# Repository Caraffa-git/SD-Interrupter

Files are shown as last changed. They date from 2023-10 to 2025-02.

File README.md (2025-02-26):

# Tesla coil MIDI interrupter
It's modified version of [OneTesla SD interrupter](https://onetesla.com/).
To compile original software you have to install [SdFat v1.1.4](https://github.com/greiman/SdFat/releases/tag/1.1.4) library.


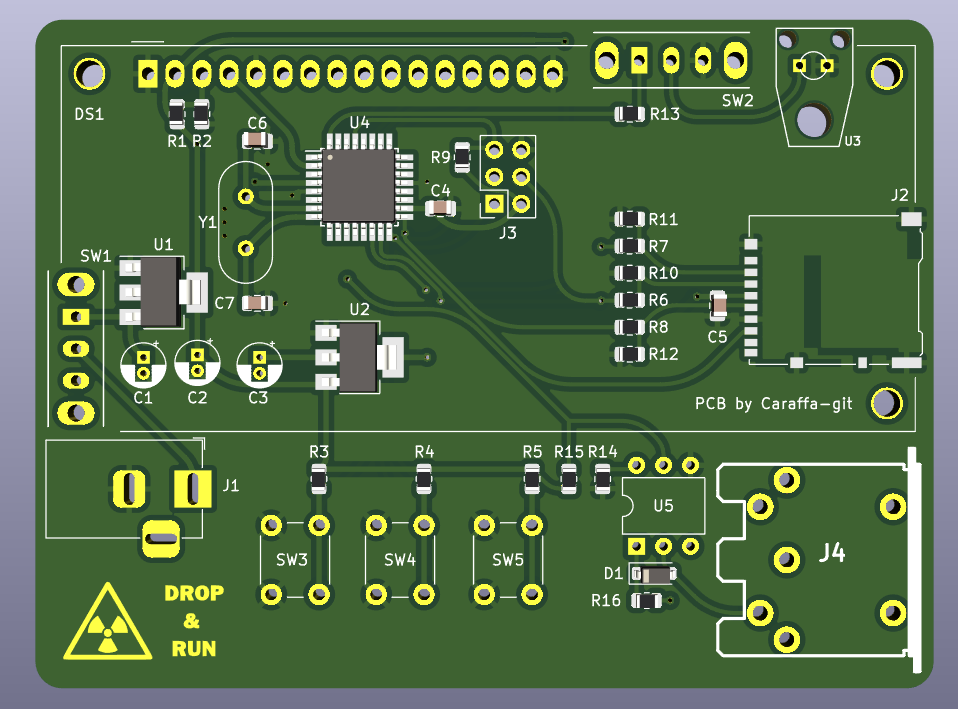
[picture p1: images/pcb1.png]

<!-- ![](./images/pcb2.png) -->

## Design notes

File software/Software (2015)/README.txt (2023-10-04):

This is the source and binary distribution for the oneTeslaTS SD card interrupter. Most users do not need to download this file - this package is useful only if you are modifying or reflashing your ATMega firmware.

==Description==

The SD card interrupter is designed to be a full-featured interrupter with support for live MIDI streaming and playback of local files stored on an SD card. Great care was taken to ensure that all source remained Arduino-compatible, and that the entire firmware would run on a single ATMega328 microcontroller. It features:

*Streaming from MIDI devices, including computers and keyboards.
*Playback of MIDI-like files ("OMD") from a micro SD card.
*Fixed mode with precise timer-based frequency control down to 1Hz.
*Small firmware size using fixed-point math, no softfloat libraries or FPU needed.

==Building==

This firmware has been developed on Arduino 1.0.3. We do not recommend using other versions due to Arduino's occasional tendency to break backwards compatibility. You will need to copy the libraries in inc/ to arduino-1.0.3/libraries. After that, it should be as simple as opening src/main/main.ino and clicking "Verify/Compile" in the Arduino IDE.

==Compatibility==

The interrupter is compatible with MicroSD/SDHC cards formatted with a FAT16 or FAT32 filesystem. Long filenames up to 99 characters are supported, as well as support for one level of directory.

==File description==

src/main
    |------ constants.h: assorted user-adjustable compile-time settings
    |------ data.h: include file for global variables
    |------ datatypes.h: program data structures
    |------ lcd.h, lcd.cpp: abstraction layer for the display; currently just a wrapper around Arduino's libraries.
    |------ main.ino: the main program loops
    |------ player.h, player.cpp: MIDI event handlers
    |------ sdsource.h, sdsource.cpp: SD card MIDI source
    |------ serialsource.h, serialsource.cpp: Hardware MIDI source
    |------ system.h, system.cpp: nonportable ATMega-specific routines
    |------ timers.h, timers.cpp: nonportable ATMega-specific ISR's
    |------ util.h, util.cpp: various utility functions

inc/
    |------ LiquidCrystal: Hitachi LCD driver library
    |------ PFFS: Petit FatFS filesystem driver
    |------ SdFat: Full featured FAT32 library

bin/
    |------ SDinterrupter.hex: pre-compiled binary for your convenience

omd/
    |------ omdconvert/
    |            |------ improv/: Improv MIDI library
    |            |------ omdconvert.exe: MIDI to OMD converter
    |            |------ omdconvert: Mac version of the converter
    |            |------ omdconvert.cpp: Source for the converter
    |            |------ README.txt: README for the converter
    |
    |------ *.mid, *.OMD: sample files

README.txt: this file :)

==CREDITS==
Props to the writers of Improv, PFFS, and SdFAT for making this possible. Special mention to Stridera on our forums, who implemented SDHC support and a bunch of neat fixes.

==LICENSING==

The libraries in inc/ are licensed under their authors' respective licensing. You are free to modify and redistribute the source and binaries found in this package for NONCOMMERCIAL USE as long as credit is given and this notice is included. Please note that in doing so, you give oneTesla, LLC nonexclusive, royalty-free license to use any such modifications for any purpose.

(We're normally not a fan of no-commercial-use source licenses as it hinders the usefulness of the code, but here we believe it is reasonable since it prevents others from unfairly mooching off our hard work while still leaving the source available for the community to use. For commerical use please contact us for further licensing terms, and we can probably work something out.)

==LEGAL DISCLAIMER==

Disclaimer of Warranty.
THERE IS NO WARRANTY FOR THE PROGRAM, TO THE EXTENT PERMITTED BY APPLICABLE LAW. EXCEPT WHEN OTHERWISE STATED IN WRITING THE COPYRIGHT HOLDERS AND/OR OTHER PARTIES PROVIDE THE PROGRAM “AS IS” WITHOUT WARRANTY OF ANY KIND, EITHER EXPRESSED OR IMPLIED, INCLUDING, BUT NOT LIMITED TO, THE IMPLIED WARRANTIES OF MERCHANTABILITY AND FITNESS FOR A PARTICULAR PURPOSE. THE ENTIRE RISK AS TO THE QUALITY AND PERFORMANCE OF THE PROGRAM IS WITH YOU. SHOULD THE PROGRAM PROVE DEFECTIVE, YOU ASSUME THE COST OF ALL NECESSARY SERVICING, REPAIR OR CORRECTION.

Limitation of Liability.
IN NO EVENT UNLESS REQUIRED BY APPLICABLE LAW OR AGREED TO IN WRITING WILL ANY COPYRIGHT HOLDER, OR ANY OTHER PARTY WHO MODIFIES AND/OR CONVEYS THE PROGRAM AS PERMITTED ABOVE, BE LIABLE TO YOU FOR DAMAGES, INCLUDING ANY GENERAL, SPECIAL, INCIDENTAL OR CONSEQUENTIAL DAMAGES ARISING OUT OF THE USE OR INABILITY TO USE THE PROGRAM (INCLUDING BUT NOT LIMITED TO LOSS OF DATA OR DATA BEING RENDERED INACCURATE OR LOSSES SUSTAINED BY YOU OR THIRD PARTIES OR A FAILURE OF THE PROGRAM TO OPERATE WITH ANY OTHER PROGRAMS), EVEN IF SUCH HOLDER OR OTHER PARTY HAS BEEN ADVISED OF THE POSSIBILITY OF SUCH DAMAGES.

If the disclaimer of warranty and limitation of liability provided above cannot be given local legal effect according to their terms, reviewing courts shall apply local law that most closely approximates an absolute waiver of all civil liability in connection with the Program, unless a warranty or assumption of liability accompanies a copy of the Program in return for a fee.

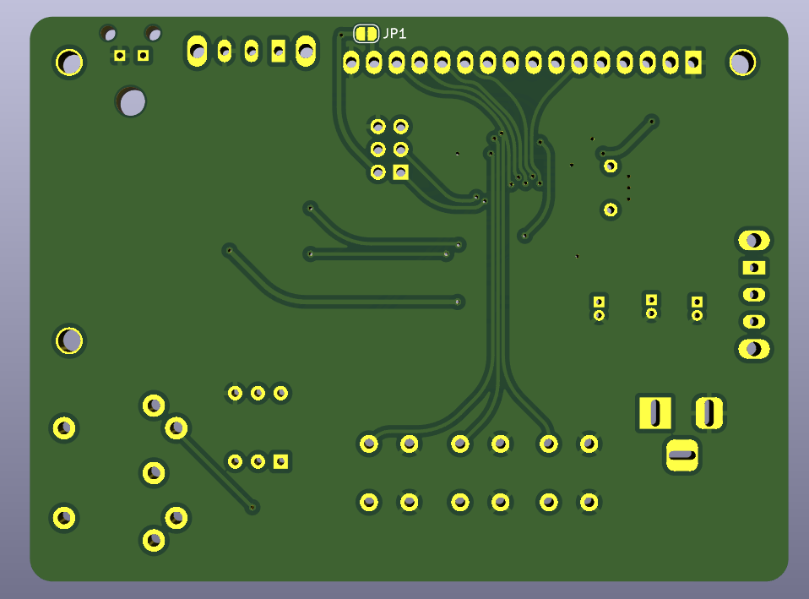
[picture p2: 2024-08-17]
images/pcb2.png

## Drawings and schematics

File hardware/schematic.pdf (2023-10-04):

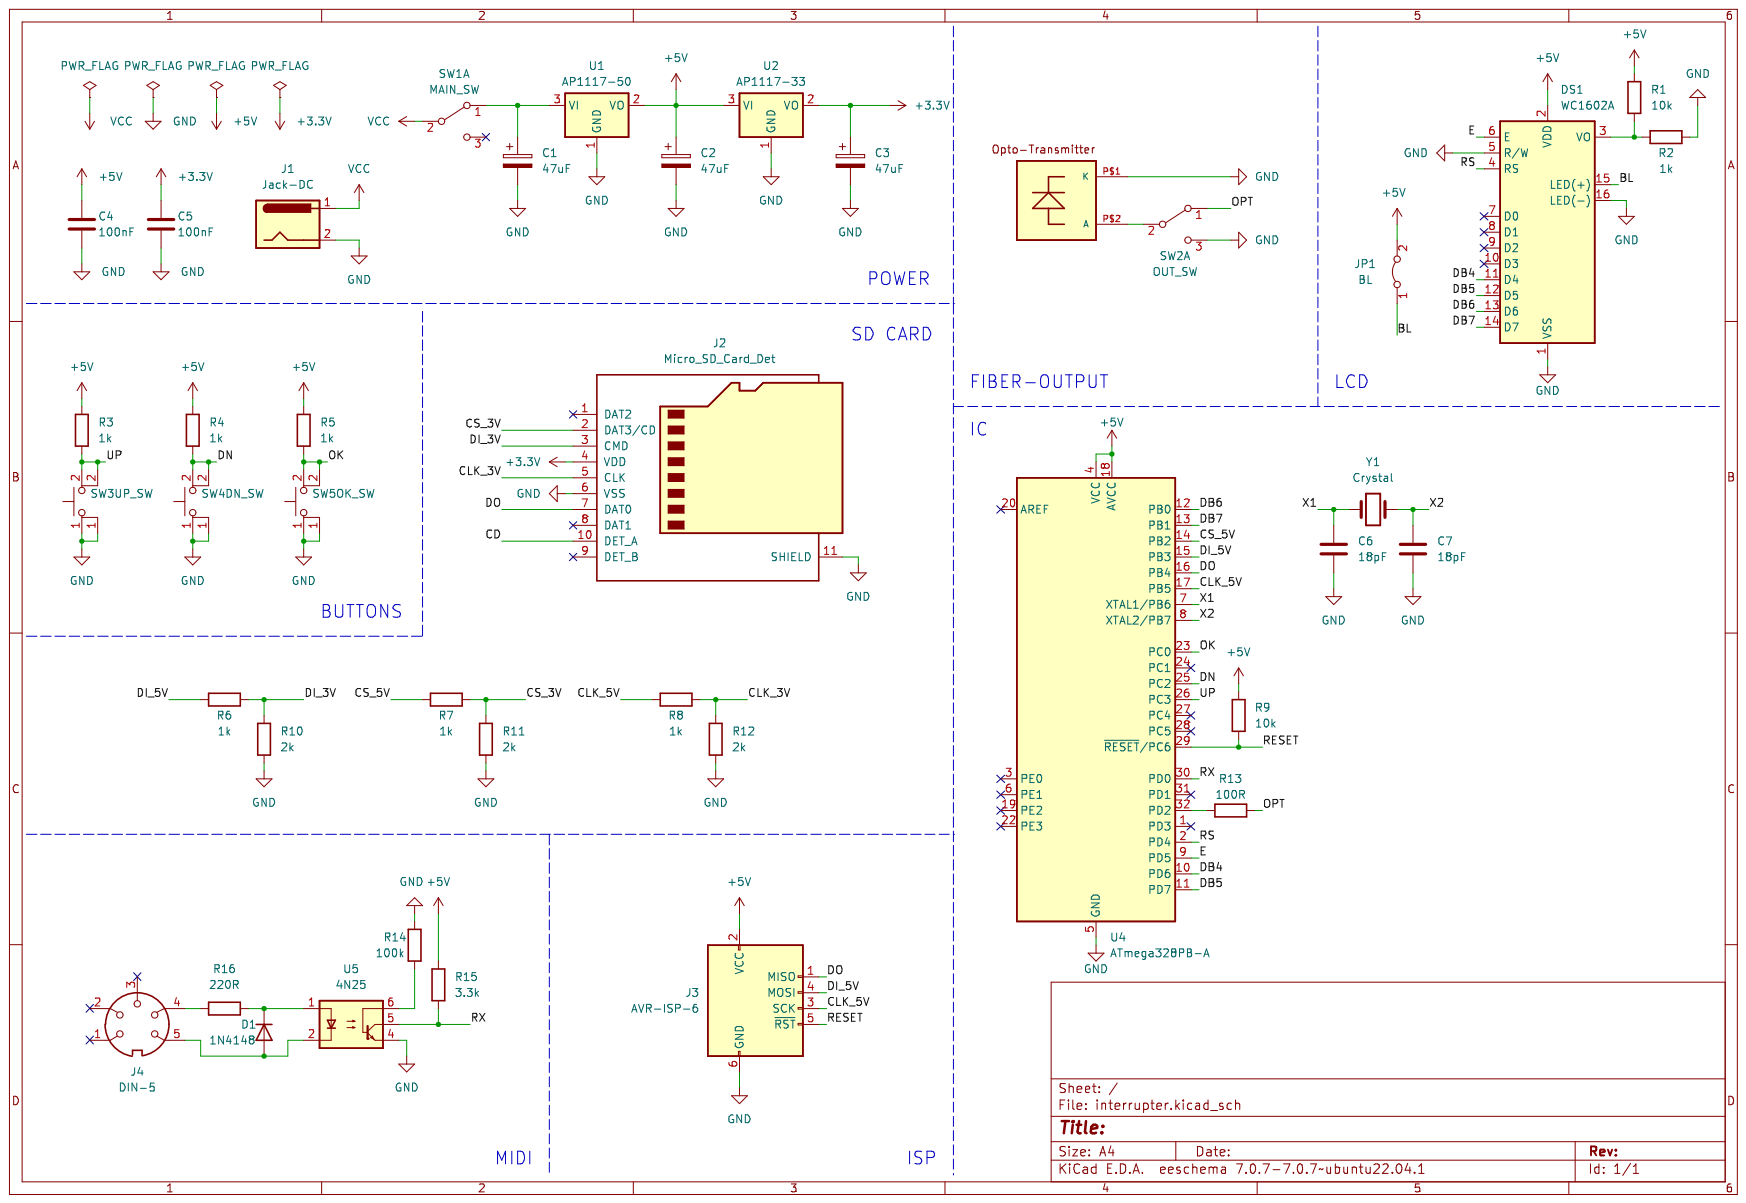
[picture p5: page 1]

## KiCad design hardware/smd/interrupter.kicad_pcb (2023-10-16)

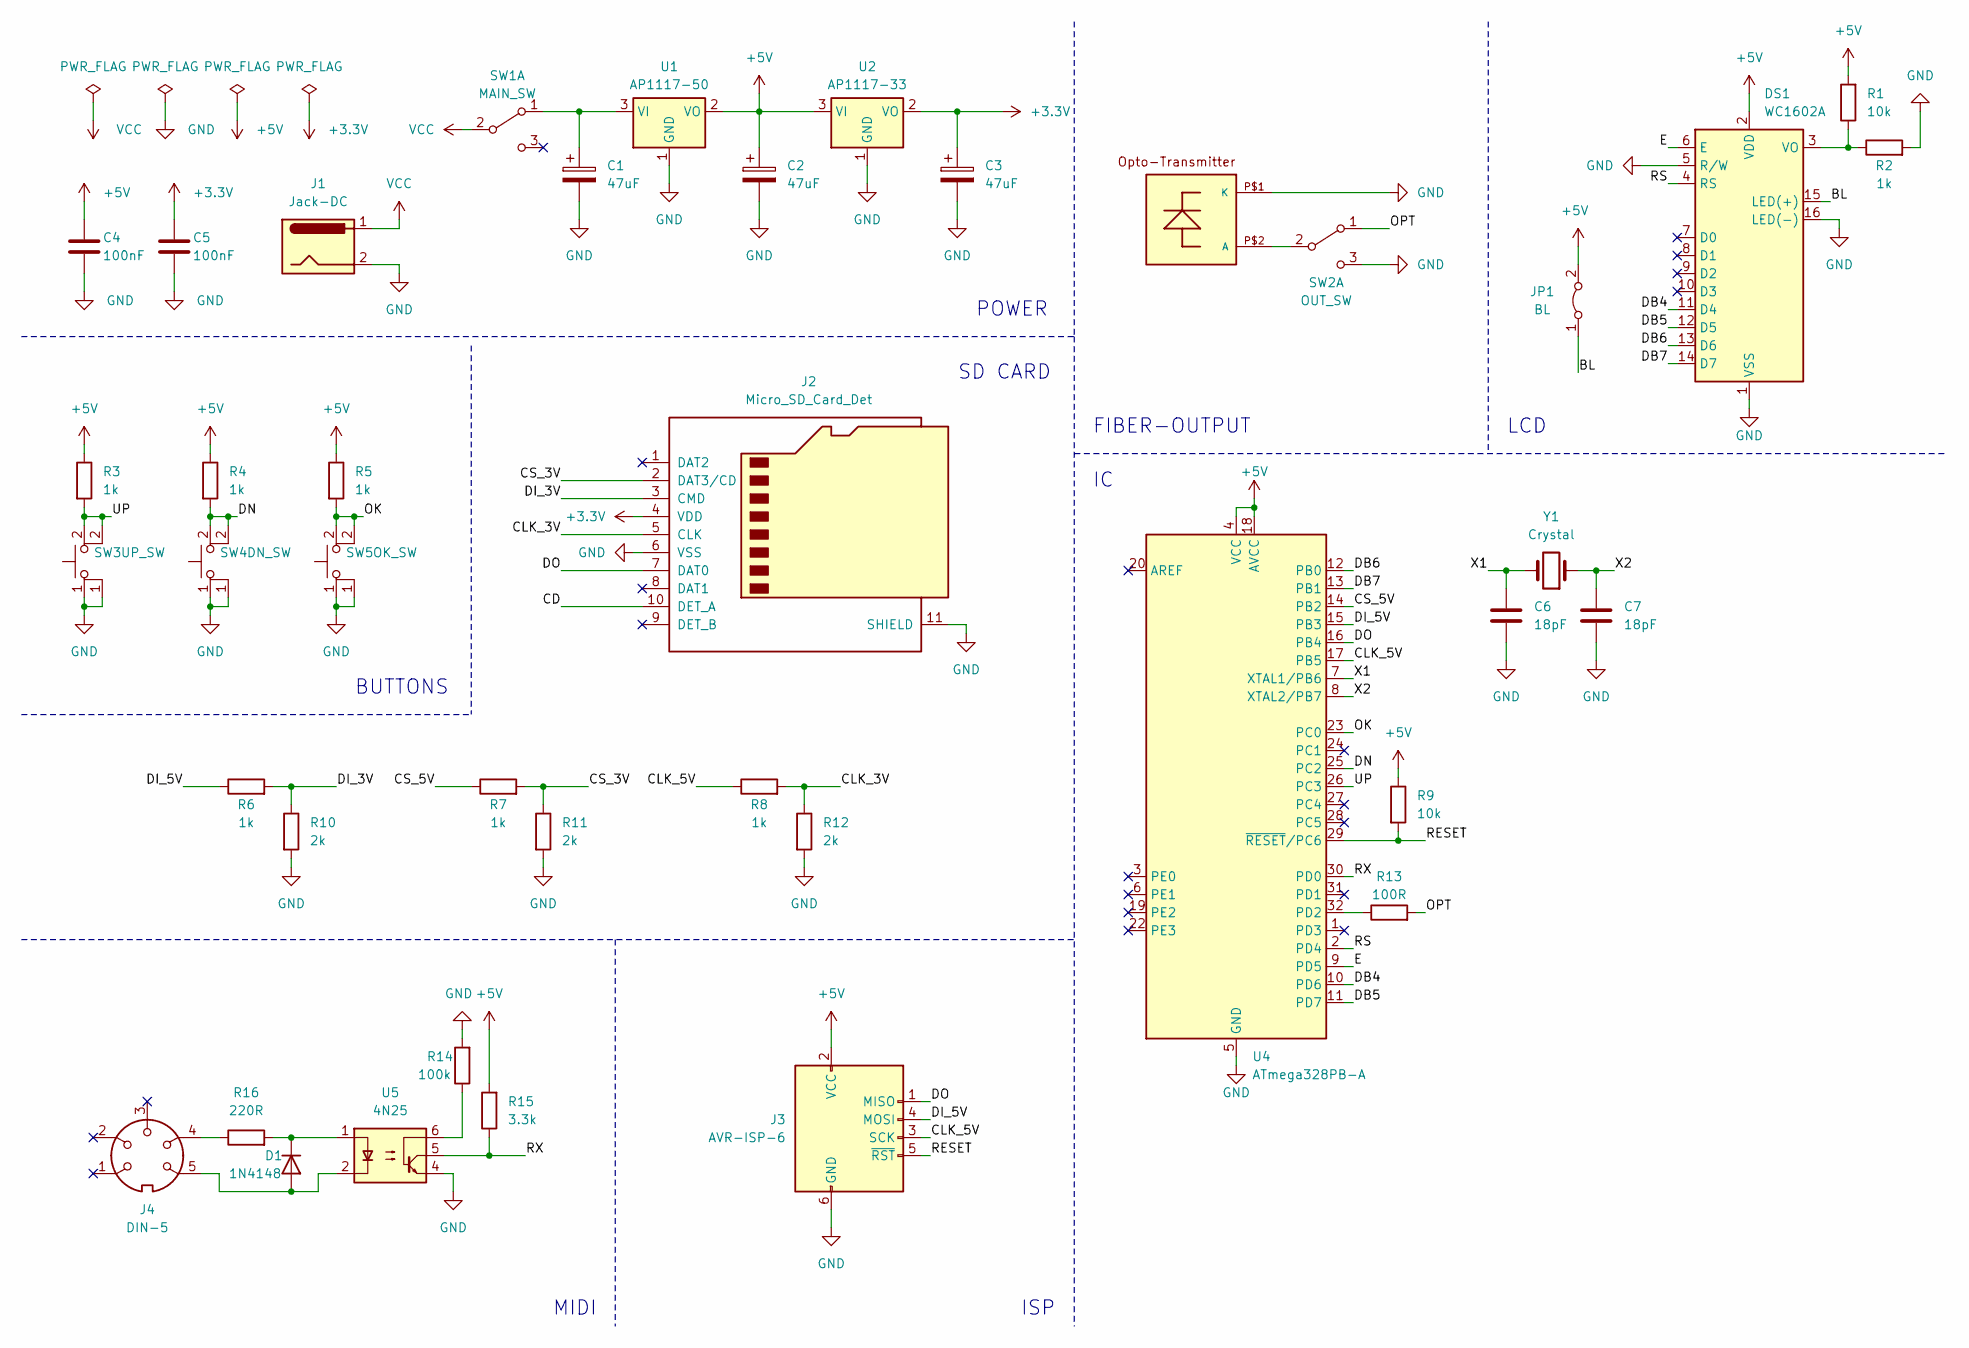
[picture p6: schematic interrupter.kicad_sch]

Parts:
C1, C2, C3: 47uF; CP_Radial_D4.0mm_P1.50mm
C4, C5: 100nF; C_0805_2012Metric
C6, C7: 18pF; C_0805_2012Metric
D1: 1N4148; D_SOD-123
DS1: WC1602A
J1: Jack-DC; BarrelJack_Horizontal
J2: Micro_SD_Card_Det; microSD_HC_Hirose_DM3AT-SF-PEJM5
J3: AVR-ISP-6; PinSocket_2x03_P2.54mm_Vertical
J4: DIN-5; din-5
JP1: BL; SolderJumper-2_P1.3mm_Bridged_RoundedPad1.0x1.5mm
R1, R9: 10k; R_0805_2012Metric
R2, R3, R4, R5, R6, R7, R8: 1k; R_0805_2012Metric
R10, R11, R12: 2k; R_0805_2012Metric
R13: 100R; R_0805_2012Metric
R14: 100k; R_0805_2012Metric
R15: 3.3k; R_0805_2012Metric
R16: 220R; R_0805_2012Metric
SW1: MAIN_SW; Switch 12x6mm
SW2: OUT_SW; Switch 12x6mm
SW3: UP_SW; SW_PUSH_6mm_H7.3mm
SW4: DN_SW; SW_PUSH_6mm_H7.3mm
SW5: OK_SW; SW_PUSH_6mm_H7.3mm
U1: AP1117-50; SOT-223-3_TabPin2
U2: AP1117-33; SOT-223-3_TabPin2
U3: IFE91A; OPTO-TRANSMITTER
U4: ATmega328PB-A; TQFP-32_7x7mm_P0.8mm
U5: 4N25; DIP-6_W7.62mm
Y1: Crystal; Crystal_HC49-4H_Vertical

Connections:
+3.3V: C3.1, C5.1, J2.4 (VDD), U2.2 (VO)
+5V: C2.1, C4.1, DS1.2 (VDD), J3.2 (VCC), JP1.2 (B), R1.2, R3.1, R4.1, R5.1, R9.1, R15.2, U1.2 (VO), U2.3 (VI), U4.4 (VCC), U4.18 (AVCC)
/BL: DS1.15 (LED(+)), JP1.1 (A)
/CD: J2.10 (DET_A)
/CLK_3V: J2.5 (CLK), R8.2, R12.1; also elsewhere on the board
/CLK_5V: J3.3 (SCK), R8.1, U4.17 (PB5)
/CS_3V: J2.2 (DAT3/CD), R7.2, R11.1
/CS_5V: R7.1, U4.14 (PB2)
/DB4: DS1.11 (D4), U4.10 (PD6)
/DB5: DS1.12 (D5), U4.11 (PD7)
/DB6: DS1.13 (D6), U4.12 (PB0)
/DB7: DS1.14 (D7), U4.13 (PB1)
/DI_3V: J2.3 (CMD), R6.2, R10.1
/DI_5V: J3.4 (MOSI), R6.1, U4.15 (PB3)
/DN: R4.2, SW4.2 (A), U4.25 (PC2)
/DO: J2.7 (DAT0), J3.1 (MISO), U4.16 (PB4)
/E: DS1.6 (E), U4.9 (PD5)
/OK: R5.2, SW5.2 (A), U4.23 (PC0)
/OPT: R13.2, SW2.1 (A)
/RESET: J3.5 (~RST), R9.2, U4.29 (~RESET/PC6)
/RS: DS1.4 (RS), U4.2 (PD4)
/RX: R15.1, U4.30 (PD0), U5.5
/UP: R3.2, SW3.2 (K), U4.26 (PC3)
/X1: C6.1, U4.7 (XTAL1/PB6), Y1.2
/X2: C7.1, U4.8 (XTAL2/PB7), Y1.1
GND: C1.2, C2.2, C3.2, C4.2, C5.2, C6.2, C7.2, DS1.1 (VSS), DS1.5 (R/W), DS1.16 (LED(-)), J1.2, J2.6 (VSS), J2.11 (SHIELD), J3.6 (GND), R2.2, R10.2, R11.2, R12.2, R14.2, SW2.3 (C), SW3.1, SW4.1, SW5.1, U1.1 (GND), U2.1 (GND), U3.P$1 (K), U4.5 (GND), U4.21 (GND), U5.4; also elsewhere on the board
unnamed: D1.2 (A), J4.5, U5.2
unnamed: D1.1 (K), R16.2, U5.1
unnamed: DS1.3 (VO), R1.1, R2.1
unnamed: J4.4, R16.1
unnamed: R14.1, U5.6
unnamed: C1.1, SW1.1 (A), U1.3 (VI)
unnamed: SW2.2 (B), U3.P$2 (A)
unnamed: R13.1, U4.32 (PD2)
VCC: J1.1, SW1.2 (B)

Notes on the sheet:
ISP
SD CARD
MIDI
POWER
FIBER-OUTPUT
LCD
BUTTONS

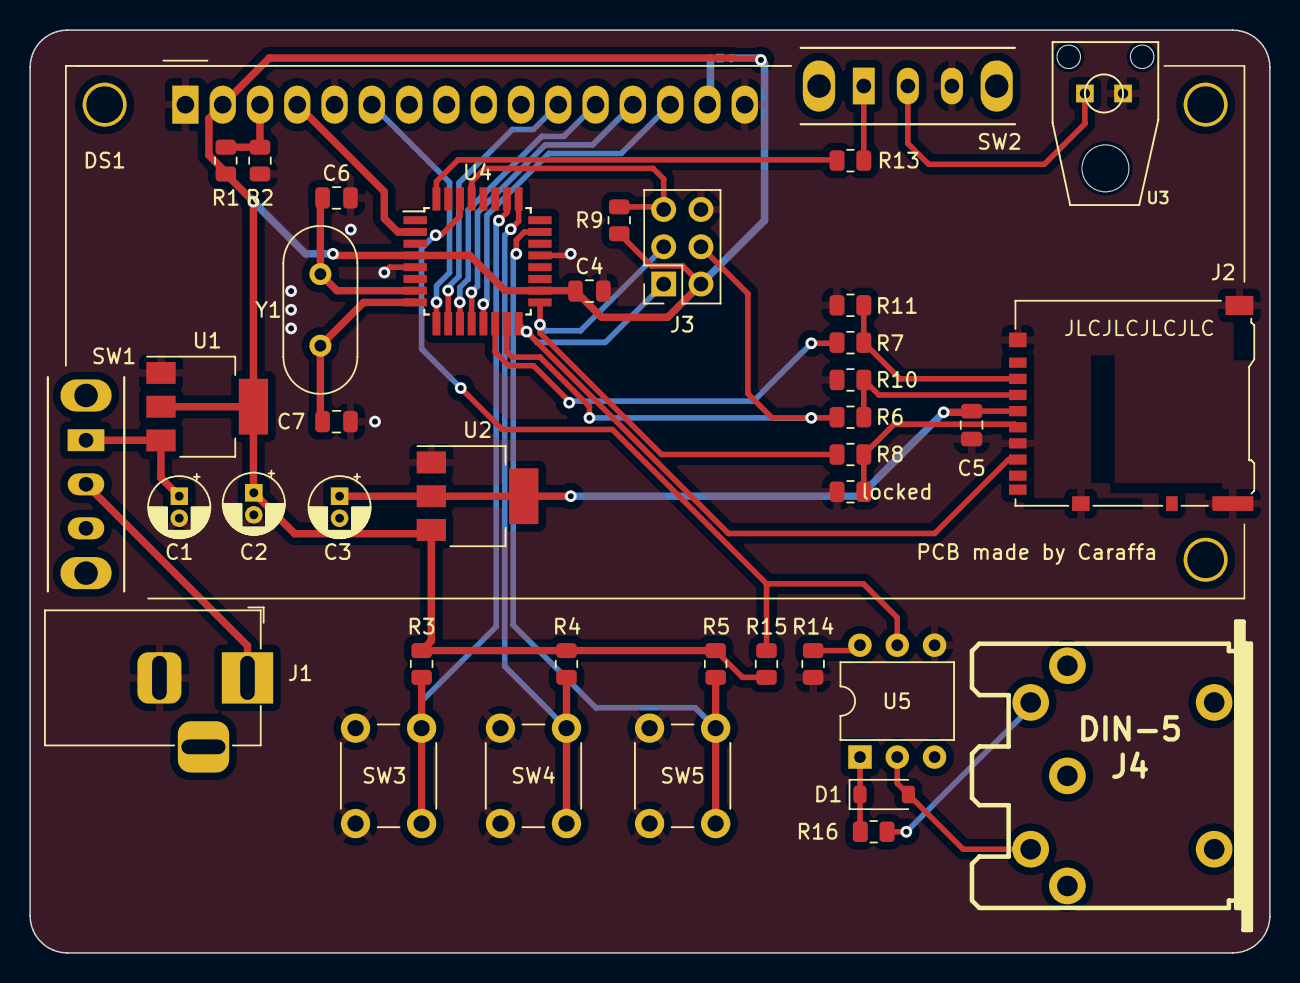
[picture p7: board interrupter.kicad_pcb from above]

Board: 2 copper layers, 84.5 x 62.9 mm, 41 parts (1 on the bottom side), 34 nets.

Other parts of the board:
locked: 2k; R_0805_2012Metric

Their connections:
/CLK_3V: locked.1; also elsewhere on the board
GND: locked.2; also elsewhere on the board

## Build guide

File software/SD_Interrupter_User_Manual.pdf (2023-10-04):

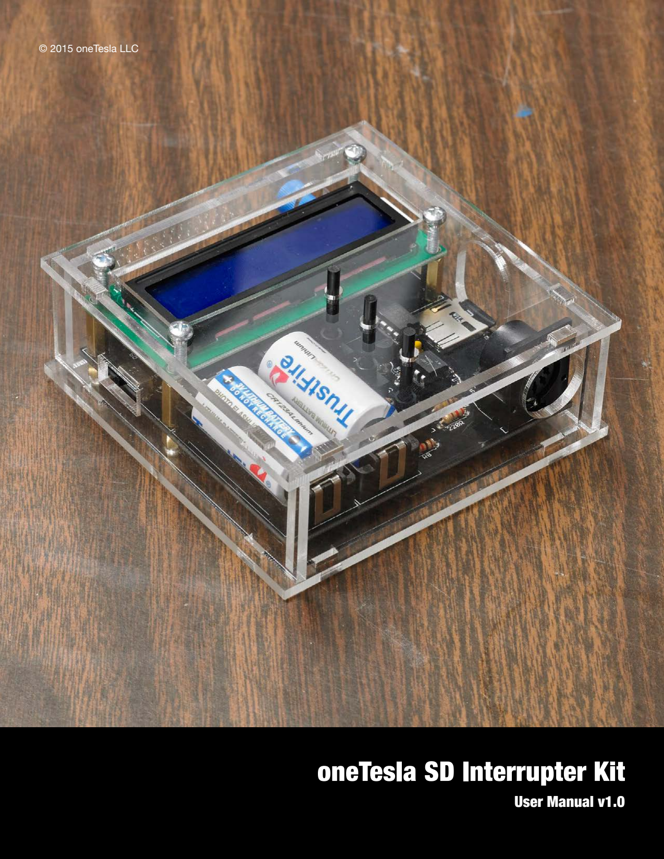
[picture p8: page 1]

# oneTesla SD Interrupter Kit

## User Manual v1.0

© 2015 oneTesla LLC

# Step 1: Assemble the SD Interrupter

Heat up your iron! Let’s start soldering. We’ll begin with the SD card interrupter because we need it working to test the Tesla coil’s electronics later on.
A. Install resistors R1 through R10. Note that in early boards, R9 is mislabeled as 1kΩ and should be 100Ω (see image)!
B. Install capacitors C1 through C5.
C. Install sockets for IC2, IC3, and IC4. Align the notch on the socket to the notch pictured on the board.
D. Install D1.
E. Install the slide switches.
F. Install the 16-pin female header for the LCD.
G. Install IC1 (a 78L05 5V regulator) and IC5 (a 3.3 V regulator). See image.
H. 16MHz crystal Y1.
I. Install the optical transmitter.
J. Install the two CR123A battery holders. Ensure that the + mark on each socket aligns with the + mark on the board!
K. Install the MIDI jack.
L. Install the tall pushbutton switches S1, S2, and S3.
M. Install the ICs in their sockets, taking care to orient them correctly.
N. Solder the male header pins into the LCD module.
O. Place the LCD module into the female header pins on the board. You don’t need to install the standoffs yet, as you should confirm that the b rd works before finishing the mechanical assembl .
P. Install the batteries, taking care to orient them correctly.
R1, R10 | 10kΩ (brown black orange)
R2, R7, R8 | 1kΩ (brown black red)
R3, R9 | 100 (brown black brown) (note that on early boards, R9 is mislabeled)
R4 | 100kΩ (brown black yellow)
R5 | 3.3kΩ (orange orange red)
R6 | 220Ω (red red brown)
C1, C2, C5 | 1uF (labeled 105)
C3, C4 | 18pF (labeled 180)
D1 | 1N4148
| 2x Slide switch
| LCD headers
IC1 | 7805
IC2 | ATMega328
IC3 | 4N25
IC4 | 74HC4050
IC5 | 3.3V regulator (note that early boards are mislabeled)
Y1 | 16MHz crystal
| Fiber optic transmitter
| 2x CR123A battery holder
J2 | MIDI jack
S1, S2, S3 | Tall tactile switch

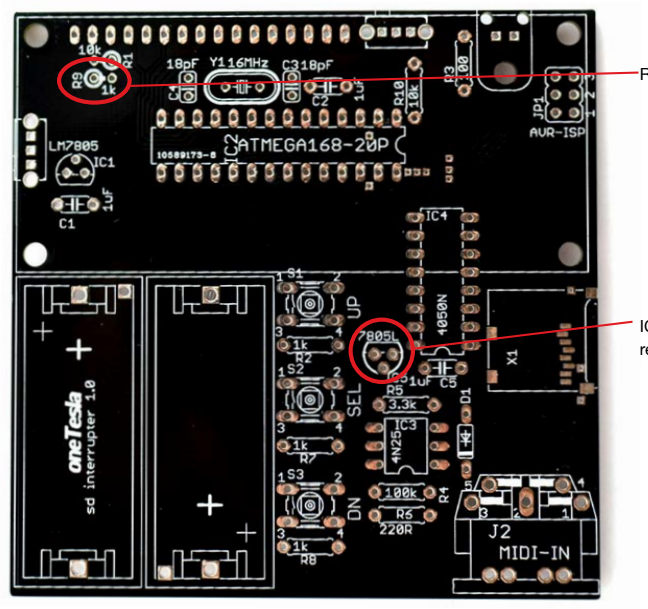
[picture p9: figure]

R9 is 100Ω

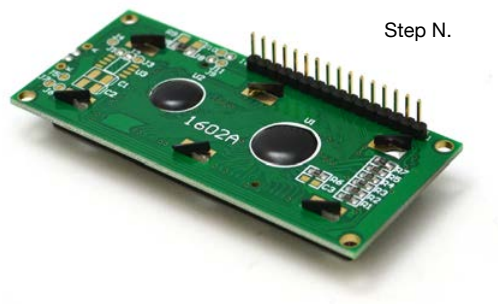
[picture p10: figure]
Step N.

IC5 is a 3.3V
regulator

# Step 2: Test the SD Interrupter

Power on the interrupter. Depending on whether or not you have a micro SD card installed, you should be greeted with either “Fixed Mode” or “No SD card found” on the display. Press [Down] until you see “Fixed Mode”, then press [Select] to launch fixed mode. Loo into the optical transmitter and verify that you see a blinking red light. If you do, hooray, your interrupter works! Proceed to step 3. If no display is
present...

If no backlight is
present...

If the display is
present but the LED
does not light...

If the buttons
don’t work...

n Make sure all ICs are correctly installed in their sockets.
n Measure the voltage between pins 7 and 8 of the ATMega328 and confirm that it is 5 volts. If it is not check for soldering errors around the 78L05 regulator and the pins of the ATMega328.
n Make sure R1 and R9 are not switched. Swapping R1 and R9 will cause extremely low contrast on the screen.
n Try switching on the backlight; in bright lighting conditions the screen may be hard to see without
a backlight.
Lack of a backlight indicates that the 5V rail is absent. Check for shorts on the board. Verify that the batteries are installed in the correct orientation.

n Check the soldering of R3 and the fiber transmitte .
n Check the ATMega328, particularly pin 4.
n Confirm that the fiber transmitter is not mechanically damage

Check the soldering of the buttons and the 1K resistors next to them. Be gentle with the buttons, as they are tall and too much sideways force will damage them.

Testing that the basic interrupter functionality works will let you test your coil. If you want to do more advanced troubleshooting go to step 17.

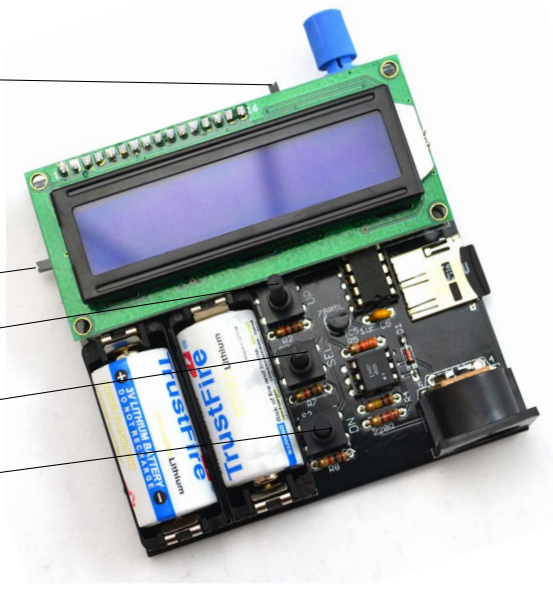
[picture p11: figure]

Backlight switch

On/Off switc

[Up]

[Select]

[Down]

Need help?
If you encounter a problem that isn’t covered here, take a look at our online help forum at onetesla.com/forum. Someone else may have had the same problem and figu ed out
a solution.

Please post on the forum rather than emailing us for support, so that everyone can learn from how you resolved your problem!

# Step 3: Assemble the Interrupter Case

A. Peel the protective paper off of the plastic parts
B. Start by attaching the board to the bottom plate of the chassis. Use the short standoffs t space the board from the bottom plate. Use 6mm screws through the acrylic to hold the standoffs in place
C. Screw the tall standoffs to the top of the short ones
D. Place the LCD screen into its socket.
E. Assemble the sides of the case by inserting the tabs into the holes in the base plate.
F. Install the top plate. Note that the buttons are slightly off-cente , so if your top plate isn’t fitting quite right, flip it a ound.
G. Use 13mm screws to hold the case together. Don’t over-tighten!
H. Optionally, place the sticker with arrow icons next to the buttons.

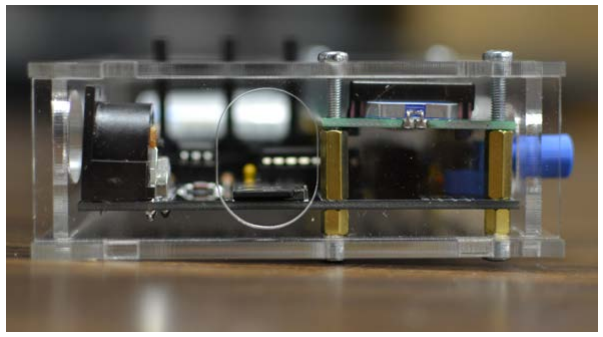
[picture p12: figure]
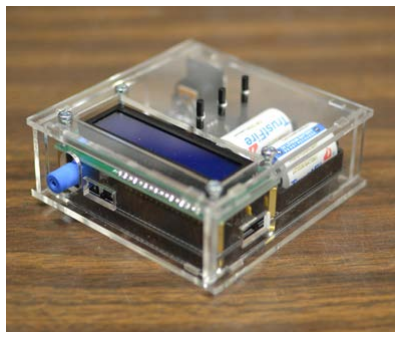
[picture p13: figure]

# STEP 4: Test advanced interrupter functions

You will need a Micro SD card of less than 2GB capacity and, if you wish to test live MIDI
functionality, a MIDI source for this step.
A. The card must be formatted as FAT. Most small SD cards likely have this file system by default, but if you are unsure, right-click on the drive and click “Properties”; the “Filesystem” entry should read FAT, not FAT32 or NTFS. If it does not, right-click, “Format”, and select FAT from the drop-down box.
B. Copy one of the sample .OMD files f om our site (onetesla.com/downloads) to the SD card.
C. Power on the interrupter. You should see “Fixed Mode” displayed on the screen. If the screen displays “No SD card found”, something is wrong.
D. Scroll down until the name of a .OMD file appears on the sc een. Press [Select]. The LED inside the transmitter should light.
E. Press [Select] again to stop the song.

The most likely error you will receive in this case is the SD card not being detected. If so, check the following:
n Your SD card is formatted as FAT, and is less than 2GB in size.
n Your SD card works and is detected by a computer.
n The 4050 IC is installed in the correct direction, and is properly seated.
n The socket for the 4050 IC is correctly soldered.
n IC5 is not a 5V regulator (early revisions of the board have a typo on the board where this IC is marked as a 78L05).

It is very unlikely that the SD card is detected but songs do not play. In this case, check the MIDI files you converted f om (which is why we suggest using one of our known-working sample files for the initial test)
If you have a MIDI source, you can test MIDI functionality as well:
A. Set your MIDI source to output on its lowest channel (usually channel 0) and connect the output to the MIDI jack on the interrupter.
B. Power on the interrupter, scroll to “Live Mode”, and select it.
C. Set your MIDI source to output a middle C. You should see the LED in the transmitter light up. It should turn off when you elease the note.
If live mode does not work, check the following:
n Confirm that your MIDI device is outputting on the cor ect channel.
n Check the soldering and direction of IC3.
n Check the soldering of R4, R5, and R6.
n Make sure D1 is installed in the correct orientation.
n Make sure the MIDI jack is correctly soldered.

schematics

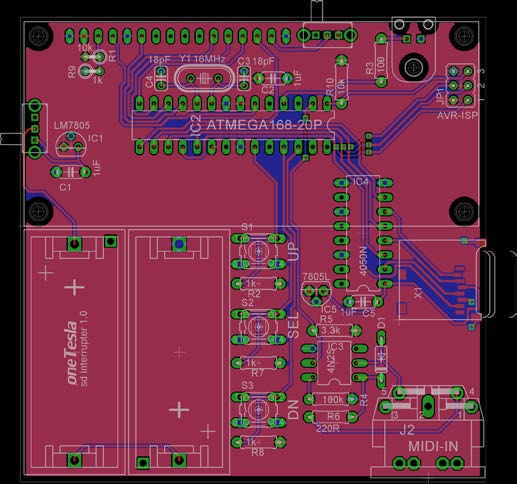
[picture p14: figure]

SD interrupter (http://www.onetesla.com)

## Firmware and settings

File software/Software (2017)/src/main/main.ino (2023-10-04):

/*
 * ATMega328 SD card interrupter
 * Copyright 2015 oneTesla, LLC
 * See README.txt for licensing information
 */
 
#include "constants.h"
#include "data.h"
#include "datatypes.h"
#include "sdsource.h"
#include "serialsource.h"
#include "player.h"
#include "system.h"
#include "util.h"
#include "timers.h"
#include "lcd.h"

#include <LiquidCrystal.h>
#include <SdFat.h>
#include <SPI.h>

LiquidCrystal lcd(RS, EN, D4, D5, D6, D7);

note *note1, *note2;
midiMsg *last_message;
serialsource *serial;
sdsource *sd;
char volindex, menuindex = 2;
int ffreq = 20;

unsigned int bfreq = 20;
unsigned int boff = 100;
unsigned int bon = 1;

void fixedLoop();
void burstLoop();
void displayMenu();

void setup() {
  lcd_init();
  setupTimers();
  setupPins();
  player_init();
  sdsource_init();
  serialsource_init();
  displayMenu();
}

void loop() {
  unsigned char key = get_key();
  if (key == btnDOWN) {
    if (menuindex == 3) {
      menuindex = 0;
    } else {
      menuindex++;
    }
    displayMenu();
    delay(180);
  }
  if (key == btnUP) {
    if (menuindex == 0) {
      menuindex = 2;
    } else {
      menuindex--;
    }
    displayMenu();
    delay(180);
  }
  if (key == btnSELECT) {
    if (menuindex == MENU_FIXED) {
      delay(150);
      fixedLoop();
      delay(300);
    } else if (menuindex == MENU_LIVE) {
      delay(150);
      lcd_printhome("Live Mode ON");
      lcd_setcursor(0, 1);
      for (int i = 0; i < volindex; i++) {
        lcd_print((char) (1));
      }
      serialsource_run();
      lcd_printhome("Live Mode");
      delay(300);
    } else if (menuindex == MENU_BURST) {
      delay(150);
      burstLoop();
      delay(300);
    } else { // MENU_SDCARD
      delay(150);
      if (sd->valid) {
        sdsource_run();
      } else {
        sdsource_initcard();
      }
      delay(300);
    }
  }
}

void displayMenu()
{
  if (menuindex == MENU_SDCARD) {
    lcd_printhome("SD Card");
    lcd_setcursor(0, 1);
    if (sd->valid) {          
      lcd_print(sd->file_count);
      if (sd->file_count == 1) {
        lcd_print(" file, ");
      } else {
        lcd_print(" files, ");
      }
      lcd_print(sd->dir_count);
      if (sd->dir_count == 1) {
        lcd_print(" dir");
      } else {
        lcd_print(" dirs");
      }
    } else {
      lcd_print((char *)sd->last_error);
    }
  } else if (menuindex == MENU_LIVE) {
    lcd_printhome("Live Mode");
  } else if (menuindex == MENU_BURST) {
    lcd_printhome("Burst Mode");
  } else {
    lcd_printhome("Fixed Mode");
  }
}

void fixedLoop() {
  lcd_printhome("[Freq: ");
  lcd_print(ffreq);
  lcd_print("Hz");
  lcd_printat(15, 0, ']');
  lcd_setcursor(0, 1);
  for (int i = 0; i < volindex; i++) {
    lcd_print((char) (1));
  }
  char mode = 1;
  unsigned long elapsed = 0;
  unsigned int uinc, dinc = 1;
  note1->velocity = 127;
  note1->on_time = get_on_time(ffreq);
  setTimer1f(ffreq);
  engageISR1();
  for (;;) {
    unsigned char key = get_key();
    if (elapsed > 100000) {
      elapsed = 0;
      if (key != btnUP) uinc = 1;
      if (key != btnDOWN) dinc = 1;
      if (key == btnSELECT) {
        mode = !mode;
        if (mode) {
          lcd_printhome("[Freq: ");
          lcd_print(ffreq);
          lcd_print("Hz");
          lcd_printat(15, 0, ']');
          lcd_setcursor(0, 1);
          for (int i = 0; i < volindex; i++) {
            lcd_print((char) (1));
          }
        } else {
          lcd_printhome("Freq: ");
          lcd_print(ffreq);
          lcd_print("Hz");
          lcd_setcursor(0, 1);
          for (int i = 0; i < volindex; i++) {
            lcd.print((char) (1));
          }
          lcd_printat(0, 1, '[');
          lcd_printat(15, 1, ']');
        }
      }
      if (key == btnUP) {
        if (!mode) {
          lcd_setcursor(0, 1);
          incvol(&lcd);
          lcd_printat(0, 1, '[');
          lcd_printat(15, 1, ']');
        } else {
          ffreq += uinc;
          uinc += 5;
          if (ffreq > 1000) ffreq = 1000;
          lcd_printat(7, 0, 7, (unsigned int) ffreq);
          lcd_print("Hz");
          note1->on_time = get_on_time(ffreq);
          setTimer1f(ffreq);
        }
      }
      if (key == btnDOWN) {
        if (!mode) {
          lcd_setcursor(0, 1);
          decvol(&lcd);
          lcd_printat(0, 1, '[');
          lcd_printat(15, 1, ']');
        } else {
          ffreq -= dinc;
          dinc += 5;
          if (ffreq < 1) ffreq = 1;
          lcd_printat(7, 0, 7, (unsigned int) ffreq);
          lcd_print("Hz");
          note1->on_time = get_on_time(ffreq);
          setTimer1f(ffreq);;
        }
      }
    }
    delayMicroseconds(1000);
    elapsed += 1000;
  }
}

void burstLoop() {
  lcd_printhome("Base Freq: ");
  lcd_printat(0, 1, bfreq);
  lcd_print(" Hz");
  int param = 0;
  
  note1->velocity = 127;
  note1->on_time = get_on_time(bfreq);
  setTimer1f(bfreq);
  engageISR1();
  
  unsigned char state = 1;
  
  unsigned long last_t_k = millis();
  unsigned long last_t_n = millis();
  for (;;) {
    unsigned long dt_k = millis() - last_t_k;
    if (dt_k > 150) last_t_k = millis();
    unsigned char key = btnNONE;
    if (dt_k > 150) key = get_key();
    
    unsigned long dt_n = millis() - last_t_n;
    unsigned long cap = state ? bon : boff;
    if (dt_n > cap) {
      if (state) {
        disengageISR1();
      } else {
        engageISR1();
      }
      state = !state;
      last_t_n = millis();
    }
    if (key == btnSELECT) {
      param++;
      if (param == 4) param = 0;
      switch (param) {
      case 0:
        lcd_printhome("Base Freq: ");
        lcd_printat(0, 1, bfreq);
        lcd_print(" Hz");
        break;
      case 1:
        lcd_printhome("Base Pwr: ");
        lcd_setcursor(0, 1);
        for (int i = 0; i < volindex; i++) {
          lcd_print((char) (1));
        }
        break;
      case 2:
        lcd_printhome("Env ON:");
        lcd_printat(0, 1, bon);
        lcd_print(" mS");
        break;
      case 3:
        lcd_printhome("Env OFF:");
        lcd_printat(0, 1, boff);
        lcd_print(" mS");
        break;
      default:
        break;
      }
    } else if (key == btnUP) {
      switch (param) {
      case 0:
        bfreq += 50;
        if (bfreq > 1000) bfreq = 1000;
        setTimer1f(bfreq);
        lcd_clear();
        lcd_printhome("Base Freq: ");
        lcd_printat(0, 1, bfreq);
        lcd_print(" Hz");
        break;
      case 1:
        incvol(&lcd);
        break;
      case 2:
        bon++;
        if (bon > 500) bon = 500;
        lcd_clear();
        lcd_printhome("Env ON:");
        lcd_printat(0, 1, bon);
        lcd_print(" mS");
        break;
      case 3:
        boff += 10;
        lcd_clear();
        lcd_printhome("Env OFF:");
        lcd_printat(0, 1, boff);
        lcd_print(" mS");
        break;
      default:
        break;
      }
    } else if (key == btnDOWN) {
      switch (param) {
      case 0:
        if (bfreq > 49) bfreq -= 50;
        setTimer1f(bfreq);
        lcd_clear();
        lcd_printhome("Base Freq: ");
        lcd_printat(0, 1, bfreq);
        lcd_print(" Hz");
        break;
      case 1:
        decvol(&lcd);
        break;
      case 2:
        if (bon > 0) bon--;
        lcd_clear();
        lcd_printhome("Env ON:");
        lcd_printat(0, 1, bon);
        lcd_print(" mS");
        break;
      case 3:
        if (boff > 9) boff -= 10;
        lcd_clear();
        lcd_printhome("Env OFF:");
        lcd_printat(0, 1, boff);
        lcd_print(" mS");
        break;
      default:
        break;
      }
    }
  }
}

int main() {
  init();
  setup();
  for(;;) {
    loop();
  }
  return 0;
}

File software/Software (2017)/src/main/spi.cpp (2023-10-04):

#include <avr/sfr_defs.h>
#include "constants.h"

byte rx()
{
  SPDR = 0xFF;
  loop_until_bit_is_set(SPSR, SPIF);
  return SPDR;
}

void tx(unsigned char d)
{
  SPDR = d;
  loop_until_bit_is_set(SPSR, SPIF);
}

void spi_init()
{
  pinMode(10, OUTPUT);
  pinMode(11, OUTPUT);
  pinMode(12, INPUT_PULLUP);
  pinMode(13, OUTPUT);
  
  SPCR = _BV(MSTR) | _BV(SPE);  // Master mode, SPI enable, clock speed MCU_XTAL/4
}


void mmc_select() {
  digitalWrite(MMC_CS, LOW);
}

void mmc_deselect() {
  digitalWrite(MMC_CS, HIGH);
}

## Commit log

2023-10-16 via fix
    [interrupter-B_Cu.gbr, interrupter-B_Mask.gbr, interrupter-B_Paste.gbr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]
2023-10-16 silkscreen fix
    [interrupter-B_Cu.gbr, interrupter-B_Mask.gbr, interrupter-B_Paste.gbr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]
